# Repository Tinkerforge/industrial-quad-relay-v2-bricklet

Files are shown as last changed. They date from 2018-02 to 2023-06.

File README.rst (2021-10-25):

Industrial Quad Relay Bricklet 2.0
==================================

This repository contains the firmware source code and the hardware design
files. The documentation generator configs can be found at
https://github.com/Tinkerforge/generators

Repository Content
------------------

software/:
 * examples/: Examples for all supported languages
 * build/: Compiled files
 * src/: Source code of firmware
 * Makefile: Makefile to build project

hardware/:
 * Contains KiCad project files and additionally schematics as PDF

datasheets/:
 * Contains datasheets for sensors and complex ICs that are used

Hardware
--------

The hardware is designed with the open source EDA Suite KiCad
(http://www.kicad.org). Before you are able to open the files,
you have to install the Tinkerforge kicad-libraries
(https://github.com/Tinkerforge/kicad-libraries). You can either clone
them directly in hardware/ or clone them in a separate folder and
symlink them into hardware/
(ln -s kicad_path/kicad-libraries project_path/hardware). After that you
can open the .pro file in hardware/ with KiCad and from there view and
modify the schematics and the PCB layout.

Software
--------

If you want to do your own Brick/Bricklet firmware development we highly
recommend that you use our build environment setup script and read the
tutorial (https://www.tinkerforge.com/en/doc/Tutorials/Tutorial_Build_Environment/Tutorial.html).

To compile the C code we recommend you to install the newest GNU Arm Embedded
Toolchain (https://launchpad.net/gcc-arm-embedded/+download).
You also need to install bricklib2 (https://github.com/Tinkerforge/bricklib2).

You can either clone it directly in software/src/ or clone it in a
separate folder and symlink it into software/src/
(ln -s bricklib_path/bricklib2 project_path/software/src/). Finally make sure to
have CMake installed (http://www.cmake.org/cmake/resources/software.html).

After that you can build the firmware by invoking make in software/.
The firmware (.zbin) can then be found in software/build/ and uploaded
with brickv (click button "Flashing" on start screen).

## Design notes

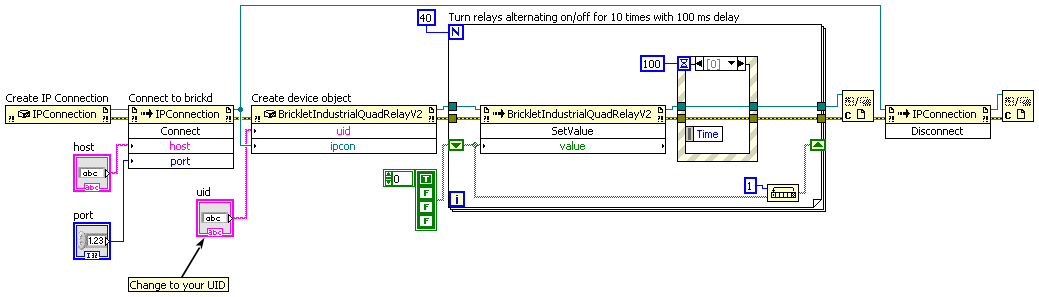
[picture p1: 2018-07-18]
software/examples/labview/Example Simple.vi.png

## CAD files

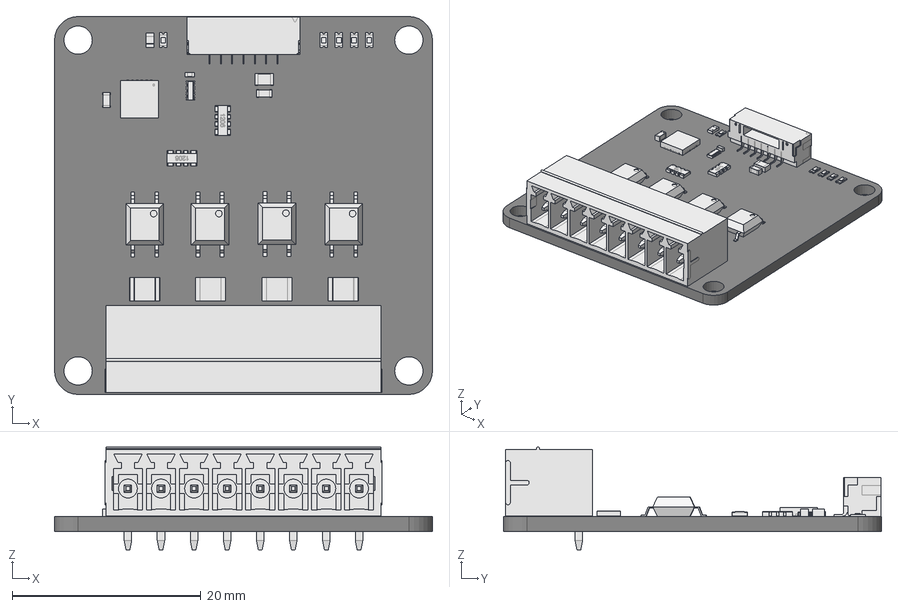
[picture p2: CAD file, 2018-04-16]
hardware/industrial-quad-relay-v2.FCStd
40.0 x 40.0 x 10.9 mm
Pcb
BrickletConn_7pin_
C_0603_
C_0402_
C_0805_
C_0603_001
D_0603_blue_
8er_Phoenix_Buchse_
R_1210_
R_1210_001
R_1210_002
R_1210_003
R_0603_
R_4x0603_
QFN-24_4x4mm_Pitch0.5mm_
SOP-4-WIDE_
SOP-4-WIDE_001
SOP-4-WIDE_002
SOP-4-WIDE_003
D_0603_blue_001
D_0603_blue_002
D_0603_blue_003
D_0603_blue_004
R_4x0603_001

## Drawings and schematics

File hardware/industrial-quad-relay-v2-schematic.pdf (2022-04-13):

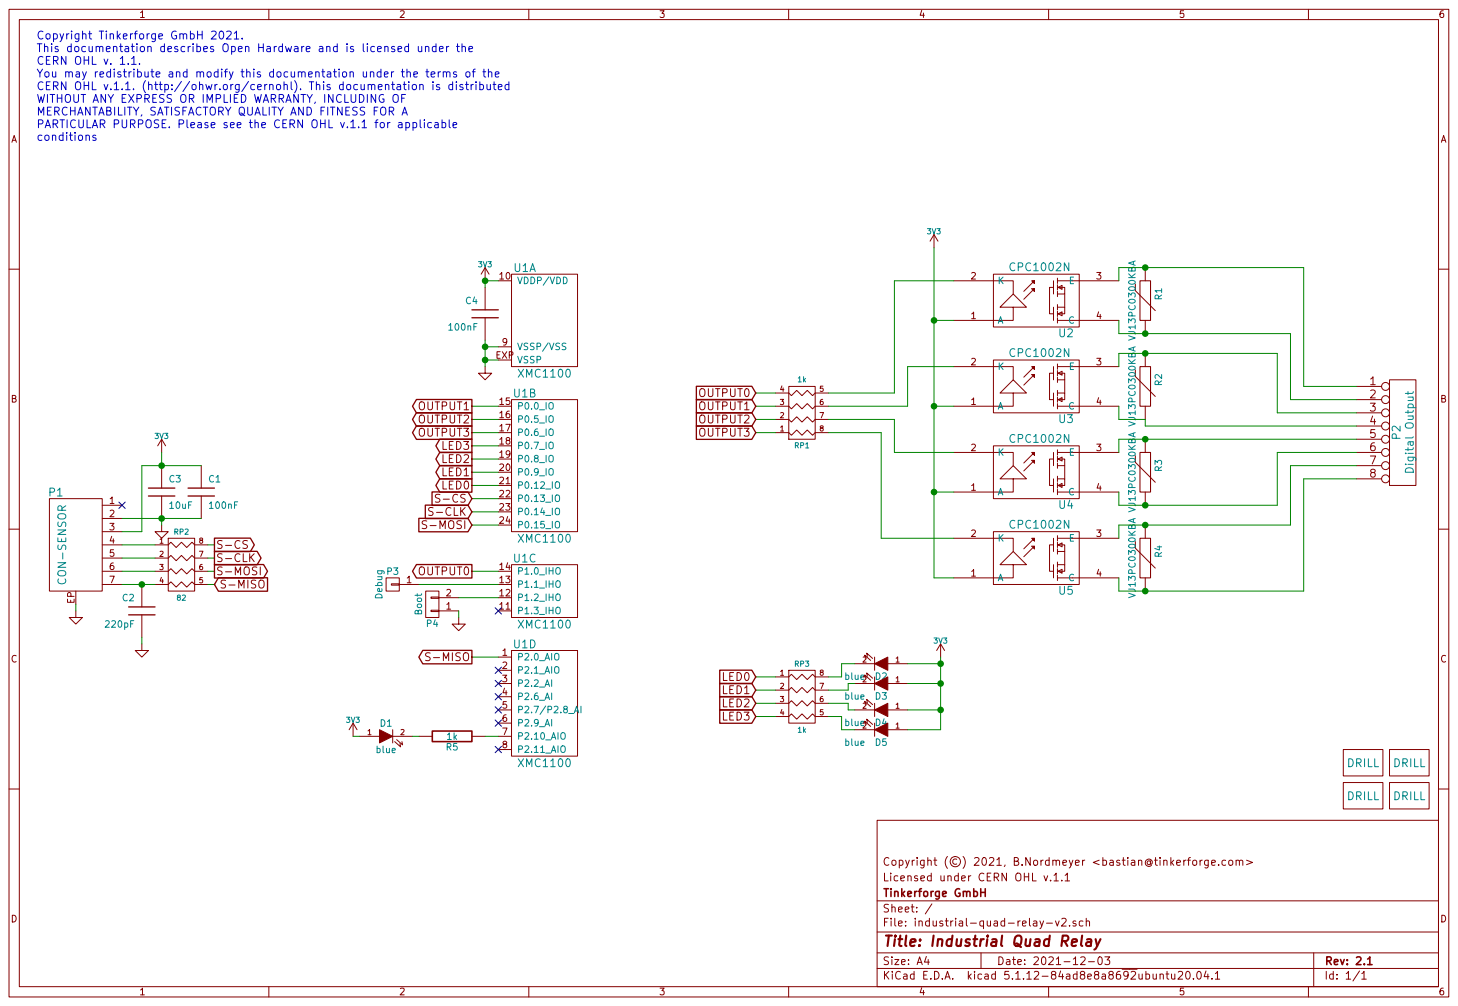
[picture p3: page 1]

Copyright Tinkerforge GmbH 2021.
This documentation describes Open Hardware and is licensed under the
CERN OHL v. 1.1.
You may redistribute and modify this documentation under the terms of the
CERN OHL v.1.1. (http://ohwr.org/cernohl). This documentation is distributed
WITHOUT ANY EXPRESS OR IMPLIED WARRANTY, INCLUDING OF
MERCHANTABILITY, SATISFACTORY QUALITY AND FITNESS FOR A
PARTICULAR PURPOSE. Please see the CERN OHL v.1.1 for applicable
conditions

Licensed under CERN OHL v.1.1 Copyright (©) 2021, B.Nordmeyer <bastian@tinkerforge.com>

File: industrial-quad-relay-v2.sch Sheet: / Tinkerforge GmbH

Id: 1/1 Title: Industrial Quad Relay

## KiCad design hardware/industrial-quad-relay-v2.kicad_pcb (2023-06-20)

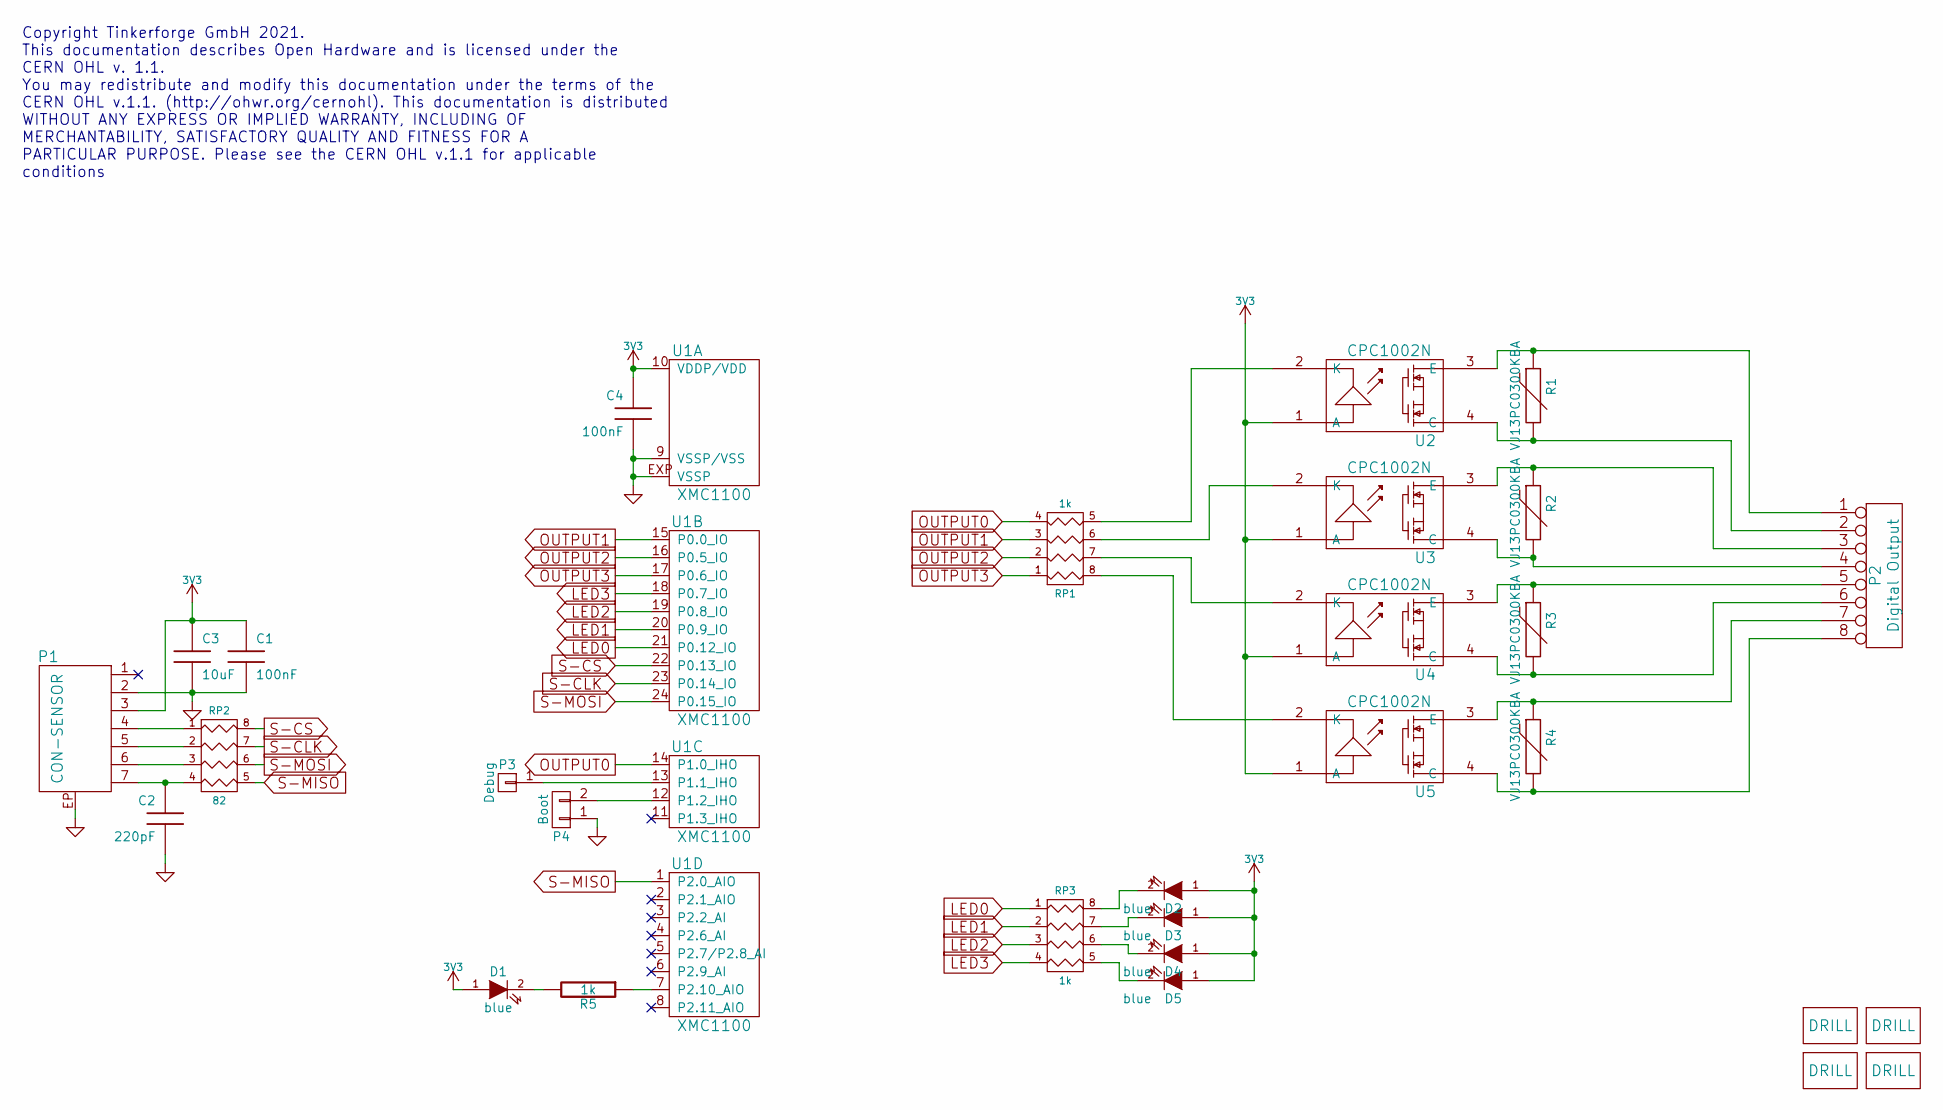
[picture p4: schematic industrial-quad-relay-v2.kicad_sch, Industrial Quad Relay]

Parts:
C1, C4: 100nF; C0603F
C2: 220pF; C0402F
C3: 10uF; C0805
D1, D2, D3, D4, D5: blue; D0603F
P1: CON-SENSOR; CON-SENSOR2
P2: Digital Output; OQ_8P
P3: Debug; DEBUG_PAD
P4: Boot; SolderJumper
R1, R2, R3, R4: VJ13PC0300KBA; R1210
R5: 1k; R0603F
RP1, RP3: 1k; 0603X4
RP2: 82; 4X0402
U1: XMC1100; QFN24-4x4mm-0.5mm
U2, U3, U4, U5: CPC1002N; SOP4-WIDE
U6, U7, U8, U9: DRILL; DRILL_NP

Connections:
3V3: C1.1, C3.1, C4.1, D1.1 (A), D2.1 (A), D3.1 (A), D4.1 (A), D5.1 (A), P1.3, U1.10 (VDDP/VDD), U2.1 (A), U3.1 (A), U4.1 (A), U5.1 (A)
GND: C1.2, C2.2, C3.2, C4.2, P1.2, P1.EP, P4.1, U1.9 (VSSP/VSS), U1.EXP (VSSP)
LED0: RP3.1, U1.21 (P0.12_IO)
LED1: RP3.2, U1.20 (P0.9_IO)
LED2: RP3.3, U1.19 (P0.8_IO)
LED3: RP3.4, U1.18 (P0.7_IO)
unnamed: C2.1, P1.7, RP2.4
unnamed: D1.2 (K), R5.2
unnamed: D2.2 (K), RP3.8 (R1)
unnamed: D3.2 (K), RP3.7 (R2)
unnamed: D4.2 (K), RP3.6 (R3)
unnamed: D5.2 (K), RP3.5 (R4)
unnamed: P1.4, RP2.1
unnamed: P1.5, RP2.2
unnamed: P1.6, RP2.3
unnamed: P2.1, R1.1, U2.3 (E)
unnamed: P2.2, R1.2, U2.4 (C)
unnamed: P2.3, R2.1, U3.3 (E)
unnamed: P2.4, R2.2, U3.4 (C)
unnamed: P2.5, R3.1, U4.3 (E)
unnamed: P2.6, R3.2, U4.4 (C)
unnamed: P2.7, R4.1, U5.3 (E)
unnamed: P2.8, R4.2, U5.4 (C)
unnamed: P3.1, U1.13 (P1.1_IHO)
unnamed: P4.2, U1.12 (P1.2_IHO)
unnamed: R5.1, U1.7 (P2.10_AIO)
unnamed: RP1.5 (R4), U2.2 (K)
unnamed: RP1.6 (R3), U3.2 (K)
unnamed: RP1.7 (R2), U4.2 (K)
unnamed: RP1.8 (R1), U5.2 (K)
OUTPUT0: RP1.4, U1.14 (P1.0_IHO)
OUTPUT1: RP1.3, U1.15 (P0.0_IO)
OUTPUT2: RP1.2, U1.16 (P0.5_IO)
OUTPUT3: RP1.1, U1.17 (P0.6_IO)
S-CLK: RP2.7 (R2), U1.23 (P0.14_IO)
S-CS: RP2.8 (R1), U1.22 (P0.13_IO)
S-MISO: RP2.5 (R4), U1.1 (P2.0_AIO)
S-MOSI: RP2.6 (R3), U1.24 (P0.15_IO)

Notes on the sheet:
Copyright Tinkerforge GmbH 2021. This documentation describes Open Hardware and is licensed under the CERN OHL v. 1.1. You may redistribute and modify this documentation under the terms of the CERN OHL v.1.1. (http://ohwr.org/cernohl). This documentation is distributed WITHOUT ANY EXPRESS OR IMPLIE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

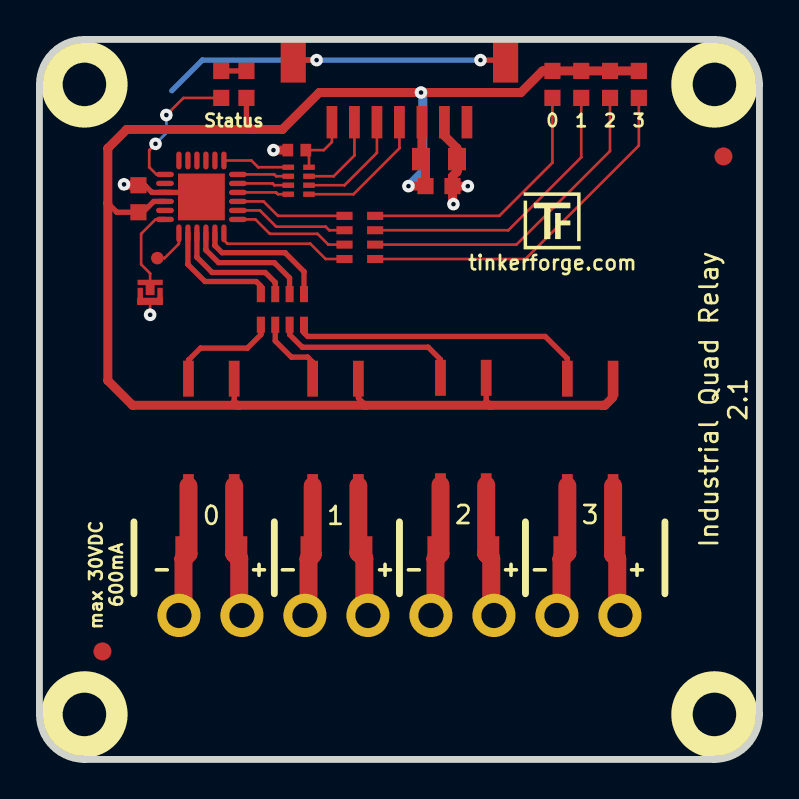
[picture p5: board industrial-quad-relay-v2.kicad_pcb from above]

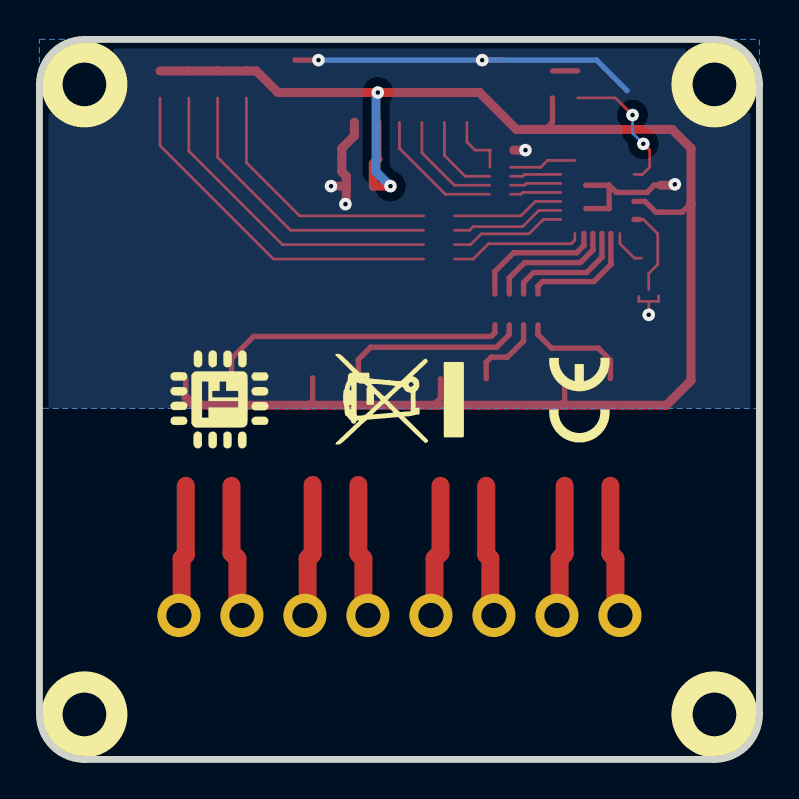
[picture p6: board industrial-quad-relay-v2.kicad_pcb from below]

Board: 2 copper layers, 40.0 x 40.0 mm, 34 parts (2 on the bottom side), 38 nets.

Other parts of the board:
Fiducial_Mark: VAL**; Fiducial_Mark
Fiducial_Mark#2: VAL**; Fiducial_Mark
VAL: WEEE_7mm
VAL#2: CE_5mm

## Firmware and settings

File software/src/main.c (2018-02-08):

/* industrial-quad-relay-v2-bricklet
 * Copyright (C) 2018 Olaf Lüke <olaf@tinkerforge.com>
 *
 * main.c: Initialization for Industrial Quad Relay V2 Bricklet
 *
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
 * You should have received a copy of the GNU Lesser General Public
 * License along with this library; if not, write to the
 * Free Software Foundation, Inc., 59 Temple Place - Suite 330,
 * Boston, MA 02111-1307, USA.
 */

#include <stdio.h>
#include <stdbool.h>

#include "configs/config.h"

#include "bricklib2/bootloader/bootloader.h"
#include "bricklib2/hal/system_timer/system_timer.h"
#include "bricklib2/logging/logging.h"
#include "communication.h"
#include "relay.h"

int main(void) {
	logging_init();
	logd("Start Industrial Quad Relay V2 Bricklet\n\r");

	communication_init();
	relay_init();

	while(true) {
		bootloader_tick();
		communication_tick();
		relay_tick();
	}
}

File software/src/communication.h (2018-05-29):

/* industrial-quad-relay-v2-bricklet
 * Copyright (C) 2018 Olaf Lüke <olaf@tinkerforge.com>
 *
 * communication.h: TFP protocol message handling
 *
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
 * You should have received a copy of the GNU Lesser General Public
 * License along with this library; if not, write to the
 * Free Software Foundation, Inc., 59 Temple Place - Suite 330,
 * Boston, MA 02111-1307, USA.
 */

#ifndef COMMUNICATION_H
#define COMMUNICATION_H

#include <stdint.h>
#include <stdbool.h>

#include "bricklib2/protocols/tfp/tfp.h"
#include "bricklib2/bootloader/bootloader.h"

// Default functions
BootloaderHandleMessageResponse handle_message(const void *data, void *response);
void communication_tick(void);
void communication_init(void);

// Constants
#define INDUSTRIAL_QUAD_RELAY_V2_CHANNEL_LED_CONFIG_OFF 0
#define INDUSTRIAL_QUAD_RELAY_V2_CHANNEL_LED_CONFIG_ON 1
#define INDUSTRIAL_QUAD_RELAY_V2_CHANNEL_LED_CONFIG_SHOW_HEARTBEAT 2
#define INDUSTRIAL_QUAD_RELAY_V2_CHANNEL_LED_CONFIG_SHOW_CHANNEL_STATUS 3

#define INDUSTRIAL_QUAD_RELAY_V2_BOOTLOADER_MODE_BOOTLOADER 0
#define INDUSTRIAL_QUAD_RELAY_V2_BOOTLOADER_MODE_FIRMWARE 1
#define INDUSTRIAL_QUAD_RELAY_V2_BOOTLOADER_MODE_BOOTLOADER_WAIT_FOR_REBOOT 2
#define INDUSTRIAL_QUAD_RELAY_V2_BOOTLOADER_MODE_FIRMWARE_WAIT_FOR_REBOOT 3
#define INDUSTRIAL_QUAD_RELAY_V2_BOOTLOADER_MODE_FIRMWARE_WAIT_FOR_ERASE_AND_REBOOT 4

#define INDUSTRIAL_QUAD_RELAY_V2_BOOTLOADER_STATUS_OK 0
#define INDUSTRIAL_QUAD_RELAY_V2_BOOTLOADER_STATUS_INVALID_MODE 1
#define INDUSTRIAL_QUAD_RELAY_V2_BOOTLOADER_STATUS_NO_CHANGE 2
#define INDUSTRIAL_QUAD_RELAY_V2_BOOTLOADER_STATUS_ENTRY_FUNCTION_NOT_PRESENT 3
#define INDUSTRIAL_QUAD_RELAY_V2_BOOTLOADER_STATUS_DEVICE_IDENTIFIER_INCORRECT 4
#define INDUSTRIAL_QUAD_RELAY_V2_BOOTLOADER_STATUS_CRC_MISMATCH 5

#define INDUSTRIAL_QUAD_RELAY_V2_STATUS_LED_CONFIG_OFF 0
#define INDUSTRIAL_QUAD_RELAY_V2_STATUS_LED_CONFIG_ON 1
#define INDUSTRIAL_QUAD_RELAY_V2_STATUS_LED_CONFIG_SHOW_HEARTBEAT 2
#define INDUSTRIAL_QUAD_RELAY_V2_STATUS_LED_CONFIG_SHOW_STATUS 3

// Function and callback IDs and structs
#define FID_SET_VALUE 1
#define FID_GET_VALUE 2
#define FID_SET_MONOFLOP 3
#define FID_GET_MONOFLOP 4
#define FID_SET_SELECTED_VALUE 5
#define FID_SET_CHANNEL_LED_CONFIG 6
#define FID_GET_CHANNEL_LED_CONFIG 7

#define FID_CALLBACK_MONOFLOP_DONE 8

typedef struct {
	TFPMessageHeader header;
	uint8_t value;
} __attribute__((__packed__)) SetValue;

typedef struct {
	TFPMessageHeader header;
} __attribute__((__packed__)) GetValue;

typedef struct {
	TFPMessageHeader header;
	uint8_t value;
} __attribute__((__packed__)) GetValue_Response;

typedef struct {
	TFPMessageHeader header;
	uint8_t channel;
	bool value;
	uint32_t time;
} __attribute__((__packed__)) SetMonoflop;

typedef struct {
	TFPMessageHeader header;
	uint8_t channel;
} __attribute__((__packed__)) GetMonoflop;

typedef struct {
	TFPMessageHeader header;
	bool value;
	uint32_t time;
	uint32_t time_remaining;
} __attribute__((__packed__)) GetMonoflop_Response;

typedef struct {
	TFPMessageHeader header;
	uint8_t channel;
	bool value;
} __attribute__((__packed__)) SetSelectedValue;

typedef struct {
	TFPMessageHeader header;
	uint8_t led;
	uint8_t config;
} __attribute__((__packed__)) SetChannelLEDConfig;

typedef struct {
	TFPMessageHeader header;
	uint8_t led;
} __attribute__((__packed__)) GetChannelLEDConfig;

typedef struct {
	TFPMessageHeader header;
	uint8_t config;
} __attribute__((__packed__)) GetChannelLEDConfig_Response;

typedef struct {
	TFPMessageHeader header;
	uint8_t channel;
	bool value;
} __attribute__((__packed__)) MonoflopDone_Callback;


// Function prototypes
BootloaderHandleMessageResponse set_value(const SetValue *data);
BootloaderHandleMessageResponse get_value(const GetValue *data, GetValue_Response *response);
BootloaderHandleMessageResponse set_monoflop(const SetMonoflop *data);
BootloaderHandleMessageResponse get_monoflop(const GetMonoflop *data, GetMonoflop_Response *response);
BootloaderHandleMessageResponse set_selected_value(const SetSelectedValue *data);
BootloaderHandleMessageResponse set_channel_led_config(const SetChannelLEDConfig *data);
BootloaderHandleMessageResponse get_channel_led_config(const GetChannelLEDConfig *data, GetChannelLEDConfig_Response *response);

// Callbacks
bool handle_monoflop_done_callback(void);

#define COMMUNICATION_CALLBACK_TICK_WAIT_MS 1
#define COMMUNICATION_CALLBACK_HANDLER_NUM 1
#define COMMUNICATION_CALLBACK_LIST_INIT \
	handle_monoflop_done_callback, \


#endif

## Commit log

2018-01-12 new hardware prototype
    [industrial-quad-relay.kicad_pcb, industrial-quad-relay.sch]
2018-01-12 fix headers
    [industrial-quad-relay.kicad_pcb]
2018-02-08 Add software for Industrial Quad Relay Bricklet 2.0
    [cmake_config_custom.txt]
2018-02-20 Cleanup KiCad libraries config
    Ensure LibDir=kicad-libraries and LibName1=tinkerforge.
    Remove special library.
2018-03-15 add four status led, routing optimized
    [industrial-quad-relay.kicad_pcb, industrial-quad-relay.sch]
2018-03-15 fix logo positions
    [industrial-quad-relay.kicad_pcb]
2018-03-16 change product name placement
    [industrial-quad-relay.kicad_pcb]
2018-03-27 specify processor
    [industrial-quad-relay.kicad_pcb, industrial-quad-relay.sch]
2018-04-11 Add info LED config support
2018-04-16 Add 3d model (*.FCStd & *.step)
    [industrial-quad-relay.FCStd]
2018-04-30 Fix pin definitions
2018-05-02 Rename info LED to channel LED
2018-05-04 Rename files
    [industrial-quad-relay-v2.FCStd, industrial-quad-relay-v2.kicad_pcb, industrial-quad-relay-v2.sch]
2018-05-04 Add schematic PDF
2018-05-04 configuration adapted to new led routing
2018-06-18 Change capacitor footprint(s) to C0402F
    [industrial-quad-relay-v2.kicad_pcb, industrial-quad-relay-v2.sch]
2019-05-02 Fix off-by-one in channel parameter range check
    [communication.c]
2019-05-07 Make monoflop time-remaining count down instead of up
    Don't use cached monoflop state, but always operate on the current state.
2020-09-02 uc: Add example driver note.
2021-10-25 Update KiCad link
    https://www.kicad.org/blog/2021/10/Avoid-links-to-former-kicad-domain/
2021-12-03 add version 2.1
    change CPC1020N -> CPC1002N
    [industrial-quad-relay-v2.kicad_pcb, industrial-quad-relay-v2.sch]
2021-12-13 add silkscreen polarity markings
    [industrial-quad-relay-v2.kicad_pcb]
2022-04-13 update schematic
2022-04-27 uc: Adapt to bindings changes
    [example_simple.c]
2023-06-20 move to new kicad version
    [industrial-quad-relay-v2.kicad_pcb, industrial-quad-relay-v2.kicad_sch, industrial-quad-relay-v2.sch]
